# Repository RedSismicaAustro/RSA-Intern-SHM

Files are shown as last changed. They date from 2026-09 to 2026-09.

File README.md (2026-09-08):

# RSA Intern SHM

Repositorio para la **migración de proyectos electrónicos desde Altium Designer hacia KiCad 10** desarrollados para el sistema **RSA Structural Health Monitoring (SHM)**.

El propósito de este repositorio es preservar los diseños electrónicos existentes, reemplazar las bibliotecas propietarias utilizadas en Altium por bibliotecas locales compatibles con KiCad y establecer un flujo de trabajo estandarizado para el mantenimiento del hardware mediante herramientas de código abierto.

Como parte del proceso de migración, cada proyecto es revisado para verificar la integridad del esquemático y del PCB, actualizar las bibliotecas de símbolos y huellas, asociar modelos tridimensionales, asignar códigos **LCSC** a los componentes compatibles con **JLCPCB** y generar nuevamente todos los archivos necesarios para fabricación y ensamblaje automático.

La documentación específica de cada tarjeta se encuentra en la carpeta **Docs**, mientras que las bibliotecas compartidas se almacenan dentro de **KiCad/libs**, permitiendo reutilizar componentes entre diferentes proyectos y garantizando que cualquier desarrollador pueda abrir los diseños sin depender de configuraciones locales.

---

# Objetivos

El proceso de migración busca establecer una metodología uniforme para todos los proyectos electrónicos del sistema SHM. Los principales objetivos del repositorio son:

- Migrar los diseños electrónicos desde Altium Designer hacia KiCad 10.
- Eliminar dependencias de bibliotecas propietarias.
- Centralizar símbolos, footprints y modelos 3D en bibliotecas locales.
- Mantener todos los proyectos bajo control de versiones mediante Git.
- Preparar los diseños para fabricación y ensamblaje mediante JLCPCB.
- Documentar el proceso de migración para facilitar futuras modificaciones y revisiones.

---

# Estructura del repositorio

El repositorio se organiza de manera que cada proyecto conserve su propia documentación, mientras que las bibliotecas compartidas permanecen centralizadas para facilitar su reutilización.

```text
RSA-Intern-SHM/
│
├── Docs/
│   ├── Nodo/
│   │   └── README.md
│   ├── Concentrador/
│   │   └── README.md
│   ├── Concentrador2/
│   │   └── README.md
│   └── ...
│
├── KiCad/
│   ├── libs/
│   │   ├── RSA.kicad_sym
│   │   ├── RSA.pretty/
│   │   ├── LibExt.pretty/
│   │   └── packages3d/
│   │
│   └── projects/
│       ├── Nodo/
│       ├── Concentrador/
│       ├── Concentrador2/
│       └── ...
│
├── Firmware/
│
├── Production/
│
└── README.md
```

La carpeta `KiCad/projects` contiene los proyectos electrónicos migrados, mientras que `KiCad/libs` almacena todas las bibliotecas compartidas utilizadas por los diferentes diseños. Esta organización evita duplicar componentes y simplifica el mantenimiento de las bibliotecas a medida que nuevos proyectos son incorporados al repositorio.

---

# Herramientas utilizadas

La migración y mantenimiento de los proyectos se realiza utilizando herramientas de código abierto y utilidades complementarias para automatizar la generación de bibliotecas y archivos de fabricación.

| Herramienta | Descripción |
|---|---|
| KiCad 10 | Diseño y edición de esquemáticos y PCB |
| Python 3 | Automatización de herramientas auxiliares |
| Git | Control de versiones |
| JLC2KiCadLib | Descarga automática de símbolos, footprints y modelos 3D |
| Fabrication Toolkit | Generación de BOM, CPL, Gerbers y NC Drill |
| JLCPCB | Fabricación y ensamblaje PCBA |

---

# Flujo de migración

Todos los proyectos contenidos en este repositorio siguen un procedimiento de migración común con el objetivo de mantener una estructura uniforme y facilitar el mantenimiento futuro.

El proceso comienza con la importación del proyecto desde Altium Designer hacia KiCad. Posteriormente se realiza una revisión completa del esquemático y del PCB para verificar que las conexiones eléctricas, las referencias de componentes y las reglas de diseño hayan sido importadas correctamente.

Una vez validado el diseño, se sustituyen las bibliotecas originales por bibliotecas locales compatibles con KiCad. Cada símbolo queda asociado con su respectiva huella y, cuando está disponible, con su modelo tridimensional.

Posteriormente se revisan los componentes para identificar aquellos compatibles con el servicio PCBA de JLCPCB. A estos componentes se les asigna su correspondiente código LCSC, permitiendo automatizar la generación de la lista de materiales y del archivo de posicionamiento durante el proceso de fabricación.

Finalmente se ejecutan las verificaciones ERC y DRC, se generan los archivos Gerber, NC Drill, BOM y CPL mediante Fabrication Toolkit y se valida la documentación obtenida utilizando el visor de JLCPCB.

---

# Organización de bibliotecas

Uno de los principales objetivos de la migración consiste en eliminar la dependencia de bibliotecas instaladas globalmente. Para ello, todos los símbolos, footprints y modelos tridimensionales utilizados por los proyectos se almacenan dentro del repositorio.

Las bibliotecas principales utilizadas son:

- RSA.kicad_sym
- RSA.pretty
- LibExt.pretty

Los modelos tridimensionales asociados a cada componente se almacenan dentro de la carpeta `packages3d`, mientras que los componentes descargados automáticamente desde JLCPCB se incorporan a las bibliotecas locales mediante **JLC2KiCadLib**.

Esta organización garantiza que cualquier proyecto pueda abrirse correctamente después de clonar el repositorio, independientemente del equipo utilizado.

---

# Proyectos

Actualmente el repositorio contiene varias tarjetas electrónicas migradas desde Altium Designer hacia KiCad 10.

| Proyecto | Descripción |
|---|---|
| Nodo | Nodo de adquisición de datos del sistema SHM. |
| Concentrador | Tarjeta concentradora de comunicaciones. |
| Concentrador2 | Segunda revisión del concentrador con mejoras de hardware. |

Cada proyecto dispone de un archivo `README.md` independiente dentro de la carpeta `Docs`, donde se documenta el procedimiento de migración, la configuración de bibliotecas, la lista de componentes, los códigos LCSC y el proceso de generación de archivos de fabricación.

---

# Preparación para fabricación

Todos los diseños fueron preparados para ser fabricados utilizando el servicio **JLCPCB PCBA**. Los componentes compatibles emplean códigos **LCSC**, permitiendo automatizar la generación de la lista de materiales y el posicionamiento de componentes durante el ensamblaje.

Antes de generar los archivos de producción se revisan las propiedades de cada componente para configurar correctamente las opciones **Exclude from BOM** y **Exclude from Board**, evitando que conectores, elementos mecánicos o componentes de montaje manual sean incluidos en los archivos de ensamblaje.

La documentación de fabricación generada para cada proyecto incluye:

- Gerber
- NC Drill
- Bill of Materials (BOM)
- Component Placement List (CPL)

Estos archivos pueden almacenarse dentro de la carpeta `Production` correspondiente a cada diseño para facilitar futuras órdenes de fabricación.

---

# Buenas prácticas

Para mantener la consistencia del repositorio se recomienda utilizar exclusivamente las bibliotecas locales almacenadas en `KiCad/libs` y evitar referencias a bibliotecas instaladas globalmente. Asimismo, cualquier componente nuevo debe incorporar su correspondiente símbolo, huella y modelo tridimensional antes de ser utilizado en un proyecto.

Se recomienda ejecutar las verificaciones ERC y DRC antes de cada liberación, mantener actualizados los códigos LCSC de los componentes compatibles con JLCPCB y validar los archivos Gerber, BOM y CPL utilizando el visor web del fabricante antes de confirmar una orden de producción.

Toda modificación realizada sobre un proyecto o una biblioteca debe registrarse mediante Git para conservar el historial de cambios y facilitar la colaboración entre los diferentes integrantes del equipo.

---

# Documentación

La documentación específica de cada tarjeta se encuentra disponible dentro de la carpeta `Docs`.

- `Docs/Nodo/README.md`
- `Docs/Concentrador/README.md`
- `Docs/Concentrador2/README.md`

Cada documento describe detalladamente el proceso de migración, los componentes utilizados, la configuración de bibliotecas, la asignación de códigos LCSC y la generación de los archivos de fabricación correspondientes.

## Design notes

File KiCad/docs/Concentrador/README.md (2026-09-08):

# Proyecto Nodo

## Migración y preparación para fabricación PCBA en KiCad 10

## Introducción

El presente documento describe el procedimiento utilizado para migrar el **Proyecto Concentrador** desde Altium Designer hacia **KiCad 10**, estandarizar las bibliotecas empleadas durante el desarrollo y preparar el diseño para su fabricación y ensamblaje automático mediante el servicio **PCBA de JLCPCB**. El objetivo principal es que cualquier desarrollador pueda clonar el repositorio, configurar el entorno de trabajo y generar nuevamente los archivos de fabricación sin depender de configuraciones locales ni de software propietario.

Durante el proceso de migración se realizó la importación del diseño electrónico, la actualización de componentes de montaje superficial, la organización de bibliotecas locales, la asignación de códigos LCSC para los componentes compatibles con JLCPCB y la generación automática de símbolos, huellas y modelos tridimensionales mediante herramientas auxiliares. Finalmente, se validó el proyecto utilizando las herramientas de fabricación de KiCad para obtener los archivos requeridos por el servicio de ensamblaje.

Toda la estructura del proyecto fue diseñada para mantener una organización uniforme dentro del repositorio Git, evitando referencias a bibliotecas externas y garantizando que todos los recursos necesarios para abrir el proyecto se encuentren almacenados localmente.

---

# Estructura del proyecto

El repositorio se organiza siguiendo una estructura modular que separa la documentación, los diseños electrónicos, las bibliotecas, el firmware y los archivos de producción. Esta organización facilita el mantenimiento del proyecto y permite reutilizar las bibliotecas en otros diseños desarrollados dentro del mismo repositorio.

```text
RSA-Intern-SHM/
│
├── Docs/
│   └── Nodo/
│       └── README.md
│
├── KiCad/
│   ├── libs/
│   │   ├── RSA.kicad_sym
│   │   ├── RSA.pretty/
│   │   │   ├── *.kicad_mod
│   │   │   └── packages3d/
│   │   └── LibExt.pretty/
│   │
│   └── projects/
│       └── concentrador2/
│
├── Firmware/
│
└── Production/
```

La carpeta **KiCad/libs** almacena todas las bibliotecas utilizadas por el proyecto. En ella se encuentran los símbolos eléctricos, las huellas de PCB y los modelos tridimensionales descargados automáticamente desde JLCPCB o desarrollados manualmente. Gracias a esta organización, cualquier persona que clone el repositorio dispondrá inmediatamente de todos los recursos necesarios para abrir el proyecto sin realizar configuraciones adicionales.

---

# Configuración del entorno

Antes de comenzar la migración es necesario preparar el entorno de desarrollo. La herramienta principal utilizada durante todo el proceso es **KiCad 10**, la cual proporciona las utilidades necesarias para editar esquemáticos, diseñar tarjetas PCB, administrar bibliotecas y generar los archivos de fabricación. Se recomienda instalar la versión estable más reciente disponible para asegurar la compatibilidad con los formatos utilizados en este proyecto.

Como complemento, se emplea **Python 3.14** para ejecutar herramientas auxiliares destinadas a la descarga automática de bibliotecas electrónicas. Se recomienda crear un entorno virtual con el fin de aislar las dependencias del proyecto y evitar conflictos con otras aplicaciones instaladas en el sistema. Para ello puede ejecutarse el siguiente comando:

```powershell
python -m venv .venv
```

Una vez creado el entorno virtual, este debe activarse antes de instalar las dependencias necesarias.

```powershell
.venv\Scripts\activate
```

Posteriormente se recomienda actualizar el administrador de paquetes para garantizar la instalación de las versiones más recientes de cada dependencia.

```powershell
pip install --upgrade pip
```

Con el entorno preparado, se procede a instalar **JLC2KiCadLib**, una utilidad desarrollada para descargar automáticamente los símbolos eléctricos, footprints y modelos tridimensionales disponibles en la base de datos de JLCPCB a partir del código LCSC de cada componente. Esta herramienta simplifica considerablemente la creación de bibliotecas y reduce el tiempo requerido para preparar nuevos diseños.

Las dependencias pueden instalarse mediante los siguientes comandos:

```powershell
pip install kicadmodtree requests
pip install JLC2KiCadLib
```

Finalmente, es recomendable verificar que la instalación se haya realizado correctamente ejecutando:

```powershell
JLC2KiCadLib --help
```

Además de las herramientas anteriores, este proyecto utiliza el complemento **Fabrication Toolkit**, disponible desde el **Plugin and Content Manager (PCM)** de KiCad. Este complemento permite automatizar la generación de la lista de materiales (BOM), el archivo de posicionamiento de componentes (CPL), los archivos Gerber y el archivo de perforaciones (NC Drill), todos ellos compatibles con el proceso de fabricación y ensamblaje de JLCPCB. Una vez instalado el complemento, únicamente es necesario reiniciar KiCad para disponer de todas sus funcionalidades.

---

# Configuración de KiCad

Con el entorno completamente instalado, el siguiente paso consiste en registrar las bibliotecas locales utilizadas por el proyecto. A diferencia de otros flujos de trabajo donde las bibliotecas se instalan globalmente, en este proyecto todos los símbolos, footprints y modelos tridimensionales permanecen dentro del repositorio. Esta estrategia garantiza que cualquier modificación realizada sobre una biblioteca quede versionada junto con el resto del proyecto y evita incompatibilidades entre diferentes estaciones de trabajo.

En el administrador de bibliotecas de símbolos (**Preferences → Manage Symbol Libraries**) debe agregarse el archivo **RSA.kicad_sym**, ubicado dentro de la carpeta **KiCad/libs**. De forma similar, desde **Preferences → Manage Footprint Libraries** debe registrarse la biblioteca **RSA.pretty**, la cual contiene todas las huellas utilizadas por el diseño.

Para evitar referencias a rutas absolutas, también se recomienda definir la variable de entorno **RSA_LIBS**, apuntando al directorio **KiCad/libs**. Gracias a esta configuración, los modelos tridimensionales podrán localizarse utilizando rutas relativas como:

```text
${RSA_LIBS}/RSA.pretty/packages3d/
```

El uso de variables de entorno facilita la portabilidad del proyecto y evita que las referencias a modelos 3D deban modificarse cuando el repositorio es clonado en un nuevo equipo. De esta forma, el proyecto mantiene una estructura consistente y completamente independiente de la ubicación física donde haya sido almacenado.

---

# Migración del proyecto

Una vez configurado el entorno de desarrollo, se procede a importar el proyecto originalmente desarrollado en Altium Designer hacia KiCad 10. Durante esta etapa es importante verificar que tanto el esquemático como el diseño de la tarjeta de circuito impreso hayan sido convertidos correctamente, prestando especial atención a las referencias entre componentes, nombres de redes, jerarquías y asociaciones entre símbolos y huellas.

Aunque KiCad incorpora herramientas de importación compatibles con proyectos de Altium, es recomendable realizar una revisión completa del diseño una vez finalizada la conversión. En particular, deben verificarse las conexiones eléctricas, las reglas de diseño (DRC), la orientación de los componentes y la correcta asociación de cada símbolo con su respectiva huella. Esta revisión permite detectar posibles inconsistencias derivadas del proceso de conversión antes de continuar con la preparación para fabricación.

Durante la migración también se reorganizaron las bibliotecas del proyecto con el propósito de eliminar dependencias externas. Los símbolos y footprints que originalmente pertenecían a bibliotecas globales fueron reemplazados por versiones almacenadas dentro de la carpeta `KiCad/libs`, garantizando que el proyecto permanezca completamente autocontenido y pueda abrirse correctamente en cualquier equipo.

---

# Adaptación de componentes para ensamblaje PCBA

Con el proyecto ya migrado, el siguiente paso consiste en adaptar los componentes para que puedan ser ensamblados automáticamente por JLCPCB. Aunque muchos componentes utilizados originalmente poseen versiones de montaje superficial (SMD), algunos dispositivos fueron reemplazados por equivalentes compatibles con el proceso de ensamblaje automático, mientras que otros permanecieron como componentes de inserción (THT) debido a restricciones mecánicas o de disponibilidad.

Cada componente fue revisado individualmente para verificar la existencia de un código **LCSC**, ya que este identificador permite relacionar el diseño electrónico con la base de datos de componentes disponible en JLCPCB. En aquellos casos donde existía un reemplazo SMD funcionalmente equivalente, se actualizó el esquemático y el PCB para utilizar dicho componente. Cuando no existía una alternativa adecuada, el componente se mantuvo como montaje manual y se excluyó del proceso de ensamblaje automático.

Este procedimiento permitió maximizar la cantidad de componentes ensamblados durante la fabricación, reduciendo considerablemente el trabajo de soldadura manual posterior.

---

# Gestión de bibliotecas y componentes

Con la selección definitiva de componentes realizada, fue necesario organizar las bibliotecas utilizadas por el proyecto. Para ello se decidió centralizar todos los recursos dentro de una única biblioteca denominada **RSA**, donde se almacenan los símbolos eléctricos, footprints y modelos tridimensionales descargados desde JLCPCB.

La descarga automática de estos recursos se realizó mediante la herramienta **JLC2KiCadLib**, la cual utiliza el código LCSC de cada componente para obtener la información necesaria desde la base de datos oficial de JLCPCB. Gracias a este procedimiento fue posible generar bibliotecas consistentes y reutilizables sin necesidad de construir manualmente cada footprint o símbolo.

El comando utilizado para descargar las bibliotecas del proyecto fue el siguiente:

```powershell
& "$env:APPDATA\Python\Python314\Scripts\JLC2KiCadLib.exe" `
C481667 `
C2651511 `
C35879 `
C720477 `
C4410 `
C17902 `
C26010 `
C17900 `
C17936 `
C2290 `
C2128 `
C1525 `
C29266 `
C15195 `
C970695 `
C2858857 `
C70381 `
-dir "C:\Users\Suarezc1224\Desktop\RSA-Intern-SHM\KiCad\libs" `
-symbol_lib RSA `
-symbol_lib_dir . `
-footprint_lib RSA.pretty `
-model_dir packages3d `
--skip_existing
```

La ejecución de este comando genera automáticamente el archivo `RSA.kicad_sym`, la biblioteca de footprints `RSA.pretty` y la carpeta `packages3d`, donde se almacenan los modelos tridimensionales utilizados por el visualizador 3D de KiCad.

Una vez descargadas las bibliotecas, se recomienda revisar cada componente para verificar que tanto el símbolo como la huella y el modelo tridimensional hayan sido asociados correctamente. En algunos casos puede ser necesario ajustar manualmente la orientación del modelo 3D o reemplazar la huella por otra versión más adecuada al diseño de la tarjeta.

---

# Componentes utilizados

Los componentes empleados durante el desarrollo del Proyecto Nodo fueron seleccionados priorizando su disponibilidad dentro del catálogo de JLCPCB y la compatibilidad con el proceso de ensamblaje automático. Para cada componente se registró su código LCSC, fabricante, encapsulado y huella correspondiente dentro de KiCad, permitiendo automatizar la generación de la lista de materiales durante la fabricación.

| Componente | Voltaje | LCSC | Type | Package | Footprint | Name |
| --- | --- | --- | --- | --- | --- | --- |
| C_470uF | 16V | C2858857 | Extended | SMD,D8xL10.2mm | Capacitor_SMD:C_Elec_8x10.2 | C1 |
| C_220uF | 16V | C970695 | Extended | SMD,D6.3xL7.7mm | Capacitor_SMD:C_Elec_6.3x7.7 | C3 |
| C_100nF | 16V | C1525 | Basic | 0402 | Capacitor_SMD:C_0402_1005Metric | C2, C4, C5, C7, C8, C12, C13, C15 |
| C_10nF | 16V | C15195 | Basic | 0402 | Capacitor_SMD:C_0402_1005Metric | C6, C9 |
| C_1uF | 16V | C29266 | Extended | 0402 | Capacitor_SMD:C_0402_1005Metric | C10 |
| D_1N4148WS | 1N4148WS | C2128 | Basic | SOD-323 | Diode_SMD:D_SOD-323 | D3 |
| D_led_white | 2.6V~3.1V 360mcd 5mA | C2290 | Basic | 0603 | LED_SMD:LED_0603_1608Metric | D2, D4, D5 |
| MAX485ED | MAX485 | C481667 | Extended | SOP-8 | Package_SO:SOIC-8_3.9x4.9mm_P1.27mm | U4, U9 |
| DS3234S# | DS3234S# | C2651511 | Extended | SO-20-300mil | Package_SO:SOIC-20W_7.5x12.8mm_P1.27mm | U5 |
| LD1117S33CTR | LD33 | C35879 | Extended | SOT-223-4 | Package_TO_SOT_SMD:SOT-223-3_TabPin2 | U3 |
| B3U-1000P | Button | C720477 | Basic | SMD,4x3mm | Button_Switch_SMD:SW_SPST_B3U-1000P | S1 |
| R_1k | Res_250mW | C4410 | Basic | 1206 | Resistor_SMD:R_1206_3216Metric | R1, R16, R18 |
| R_3.3k | Res_125mW | C26010 | Basic | 0805 | Resistor_SMD:R_0805_2012Metric | R2, R5, R13, R14 |
| R_4.7k | Res_250mW | C17936 | Basic | 1206 | Resistor_SMD:R_1206_3216Metric | R3 |
| R_10k | Res_250mW | C17902 | Basic | 1206 | Resistor_SMD:R_1206_3216Metric | R15, R17 |
| R_100k | Res_250mW | C17900 | Basic | 1206 | Resistor_SMD:R_1206_3216Metric | R4 |
| CR1220 Battery Holder | CR1220 | C70381 | Extended | CR1220 | CR1220:CR1220-2 | BT2 |

La utilización de códigos LCSC simplifica el proceso de fabricación, ya que JLCPCB puede identificar automáticamente cada componente durante la generación de la orden de ensamblaje, reduciendo errores y evitando la selección manual de referencias equivalentes.

---

# Componentes sin código LCSC

No todos los dispositivos presentes en el proyecto forman parte del catálogo de componentes de JLCPCB. Algunos elementos corresponden a conectores, microcontroladores especializados o componentes mecánicos que deben instalarse manualmente una vez recibida la tarjeta ensamblada.

Estos componentes permanecen dentro del esquemático y del diseño PCB, pero no participan en el proceso automático de ensamblaje.

| Componente | Observación |
|---|---|
| dsPIC33EP256MC202 | Instalación manual |
| Pin Header 2x20 | Instalación manual |
| Pin Header 1x02 | Instalación manual |
| Conector RJ45 | Instalación manual |

La exclusión de estos dispositivos del proceso de ensamblaje no afecta la generación de la lista de materiales, siempre que se encuentren correctamente configurados mediante los campos correspondientes dentro del esquemático.

---

# Configuración de los campos del esquemático

Antes de generar los archivos de fabricación es recomendable revisar los campos asociados a cada componente del esquemático. Durante la migración desde Altium es habitual que se conserven propiedades provenientes de diferentes proveedores o herramientas de simulación que no aportan información relevante para el proceso de fabricación. Mantener únicamente los campos necesarios simplifica el mantenimiento del proyecto, evita información duplicada y facilita la generación de la lista de materiales.

Para este proyecto se conservaron únicamente los campos requeridos por KiCad, por el proceso de ensamblaje de JLCPCB y por las herramientas de simulación integradas. En consecuencia, cada componente debe contener únicamente los siguientes campos:

| Campo | Descripción |
|---|---|
| Reference | Identificador del componente. |
| Value | Valor o referencia comercial del componente. |
| Footprint | Huella utilizada en el PCB. |
| Datasheet | Hoja de datos del fabricante. |
| Description | Descripción del componente. |
| Qty | Cantidad utilizada en el proyecto. |
| # | Número de referencia interno. |
| LCSC | Código del componente en JLCPCB. |
| MANUFACTURER | Fabricante del componente. |
| MANUFACTURER_PART_NUMBER | Número de parte del fabricante. |
| PACKAGE | Encapsulado físico. |
| Sim.Device | Configuración de simulación. |
| Sim.Pins | Asociación de pines para simulación. |
| Sim.Type | Tipo de dispositivo para simulación. |
| DNP | Indica si el componente no debe ensamblarse. |
| Exclude from BOM | Excluye el componente de la lista de materiales. |
| Exclude from Board | Excluye el componente del PCB. |

Todos los demás campos, especialmente aquellos relacionados con distribuidores externos como Digi-Key, Mouser, Farnell, Newark, Purchase URL o referencias equivalentes, fueron eliminados para mantener una estructura uniforme en todo el proyecto. Esta limpieza facilita la edición del esquemático y evita inconsistencias durante la generación automática de la documentación de fabricación.

> **Nota:** Se recomienda incluir en esta sección la captura de pantalla correspondiente a la configuración de campos utilizada durante el desarrollo del proyecto.

---

# Generación de archivos de fabricación

Una vez verificado el esquemático y completada la asignación de códigos LCSC, el proyecto se encuentra listo para generar la documentación necesaria para fabricación y ensamblaje. Para ello se emplea el complemento **Fabrication Toolkit**, integrado en KiCad, el cual automatiza la generación de todos los archivos requeridos por JLCPCB. Antes de ello es importante excluir los elementos necesarios de los archivos de producción dentro de las propiedades del elemento.
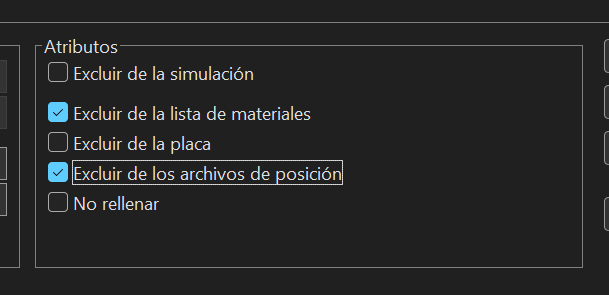
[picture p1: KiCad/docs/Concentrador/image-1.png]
Configuración de exclusión de componentes


Desde el editor de PCB se ejecuta el complemento y se selecciona el fabricante **JLCPCB** como destino. A continuación se generan de forma automática los archivos Gerber, el archivo de perforaciones (NC Drill), la lista de materiales (BOM) y el archivo de posicionamiento de componentes (CPL). El uso de esta herramienta garantiza que todos los archivos sean compatibles con el formato esperado por el servicio de fabricación, reduciendo significativamente la posibilidad de errores derivados de configuraciones manuales.

Una vez generados los archivos, se recomienda almacenarlos dentro de la carpeta `Production` del repositorio. De esta manera, toda la documentación relacionada con la fabricación permanece organizada y puede recuperarse fácilmente para futuras revisiones o nuevas órdenes de producción.
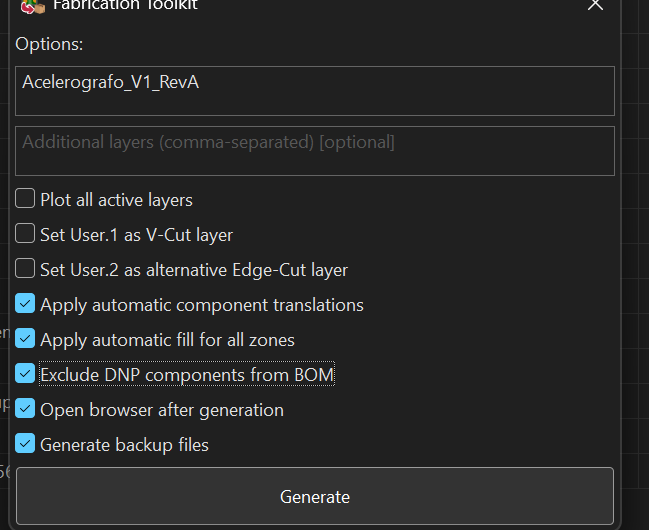
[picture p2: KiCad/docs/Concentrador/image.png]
Generación de archivos mediante Fabrication Toolkit


---

# Validación en JLCPCB

Antes de enviar el diseño a fabricación es recomendable realizar una validación completa utilizando el visor web de JLCPCB. Durante esta etapa se verifica que todos los componentes reconocidos mediante el código LCSC aparezcan correctamente asociados y que las orientaciones indicadas en el archivo CPL coincidan con la disposición física del PCB.

Asimismo, deben revisarse cuidadosamente las capas del diseño, el contorno de la tarjeta, los orificios de montaje, las dimensiones generales y cualquier advertencia generada por la plataforma de fabricación. En caso de detectarse componentes con orientación incorrecta, estos pueden corregirse directamente en KiCad y volver a generar el archivo CPL sin necesidad de modificar el resto de la documentación.

Esta validación constituye el último paso antes de confirmar la orden de fabricación y permite reducir considerablemente la probabilidad de errores durante el ensamblaje automático.

---

# Buenas prácticas

Durante el desarrollo del proyecto se adoptaron una serie de prácticas orientadas a facilitar el mantenimiento del repositorio y garantizar la reproducibilidad del diseño. Todas las bibliotecas utilizadas se almacenan localmente dentro del repositorio, evitando dependencias con bibliotecas instaladas en el sistema operativo. De igual forma, se emplean variables de entorno para referenciar los modelos tridimensionales, permitiendo que el proyecto pueda abrirse correctamente desde cualquier ubicación sin modificar rutas internas.

Se recomienda mantener actualizadas las bibliotecas únicamente cuando sea necesario incorporar nuevos componentes y evitar modificar las huellas descargadas automáticamente, salvo que exista una justificación técnica. En caso de requerir modificaciones específicas, es preferible crear una copia dentro de la biblioteca local para preservar la integridad de los componentes originales.

Finalmente, antes de cada liberación del proyecto, es aconsejable ejecutar las verificaciones ERC y DRC de KiCad, comprobar la correspondencia entre el esquemático y el PCB, revisar la lista de materiales generada y validar nuevamente los archivos de fabricación mediante el visor de JLCPCB.

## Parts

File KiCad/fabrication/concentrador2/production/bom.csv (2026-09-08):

Designator | Footprint | Quantity | Value | LCSC Part #
BT2 | CR1220-2-ext | 1 | Battery | C70381
C1 | C_Elec_8x10.2 | 1 | 470uF | C2858857
C10 | 0402 | 1 | 1uF | C29266
C12, C13, C15, C2, C4, C5, C7, C8 | 0402 | 8 | 100nF | C1525
C3 | C_Elec_6.3x7.7 | 1 | 220uF | C970695
C6, C9 | 0402 | 2 | 10nF | C15195
D2, D4, D5 | 0603 | 3 | LED_white | C2290
D3 | D_SOD-323 | 1 | 1N4148WS | C2128
R1, R16, R18 | 1206 | 3 | 1K | C4410
R13, R14, R2, R5 | 0805 | 4 | 3K3 | C26010
R15, R17 | 1206 | 2 | 10k | C17902
R3 | 1206 | 1 | 4K7 | C17936
R4 | 1206 | 1 | 100K | C17900
S1 | SW_SPST_B3U-1000P | 1 | SW-PB | C720477
U3 | SOT-223-3_TabPin2 | 1 | LD33V | C35879
U4, U9 | SOIC-8_3.9x4.9mm_P1.27mm | 2 | MAX485 | C481667
U5 | SOIC-20W_7.5x12.8mm_P1.27mm | 1 | DS3234S# | C2651511

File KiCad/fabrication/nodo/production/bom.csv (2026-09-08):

Designator | Footprint | Quantity | Value | LCSC Part #
C1 | C_Elec_8x10.2 | 1 | Cap | C2858857
C10 | 0402 | 1 | Cap | C29266
C11, C13, C16, C2, C4, C5, C7, C8 | 0402 | 8 | Cap | C1525
C3 | C_Elec_6.3x7.7 | 1 | Cap | C970695
C6, C9 | 0402 | 2 | Cap | C15195
D1 | D_SOD-323 | 1 | 1N4148WS | C2128
D3 | 0603 | 1 | LED3 | C2290
J1 | microSD | 1 | ${ALTIUM_VALUE}${VALUEAUX}
J2, J3 | RJ45_Amphenol_54602-x08_Horizontal | 2 | 54602-908LF
P1 | HDR1X6 | 1 | Grabador
R1, R13, R14, R2 | 1206 | 4 | Res1 | C26010
R3 | 1206 | 1 | Res1 | C17936
R4 | 1206 | 1 | Res1 | C17902
R6 | 1206 | 1 | Res1 | C4410
U1 | MCHP-SPDIP-SP28 | 1 | DSPIC33EP256MC202-I/SP
U2 | TO-252-3_TabPin2 | 1 | LM1117DT-5.0NOPB | C354068
U3 | SOT-223-3_TabPin2 | 1 | LD33V | C35879
U4 | ADXL355Z | 1 | ADXL355Z
U5, U9 | SOIC-8_3.9x4.9mm_P1.27mm | 2 | MAX485 | C481667
U6 | TO-263-2 | 1 | LM7805_TO220 | C15077

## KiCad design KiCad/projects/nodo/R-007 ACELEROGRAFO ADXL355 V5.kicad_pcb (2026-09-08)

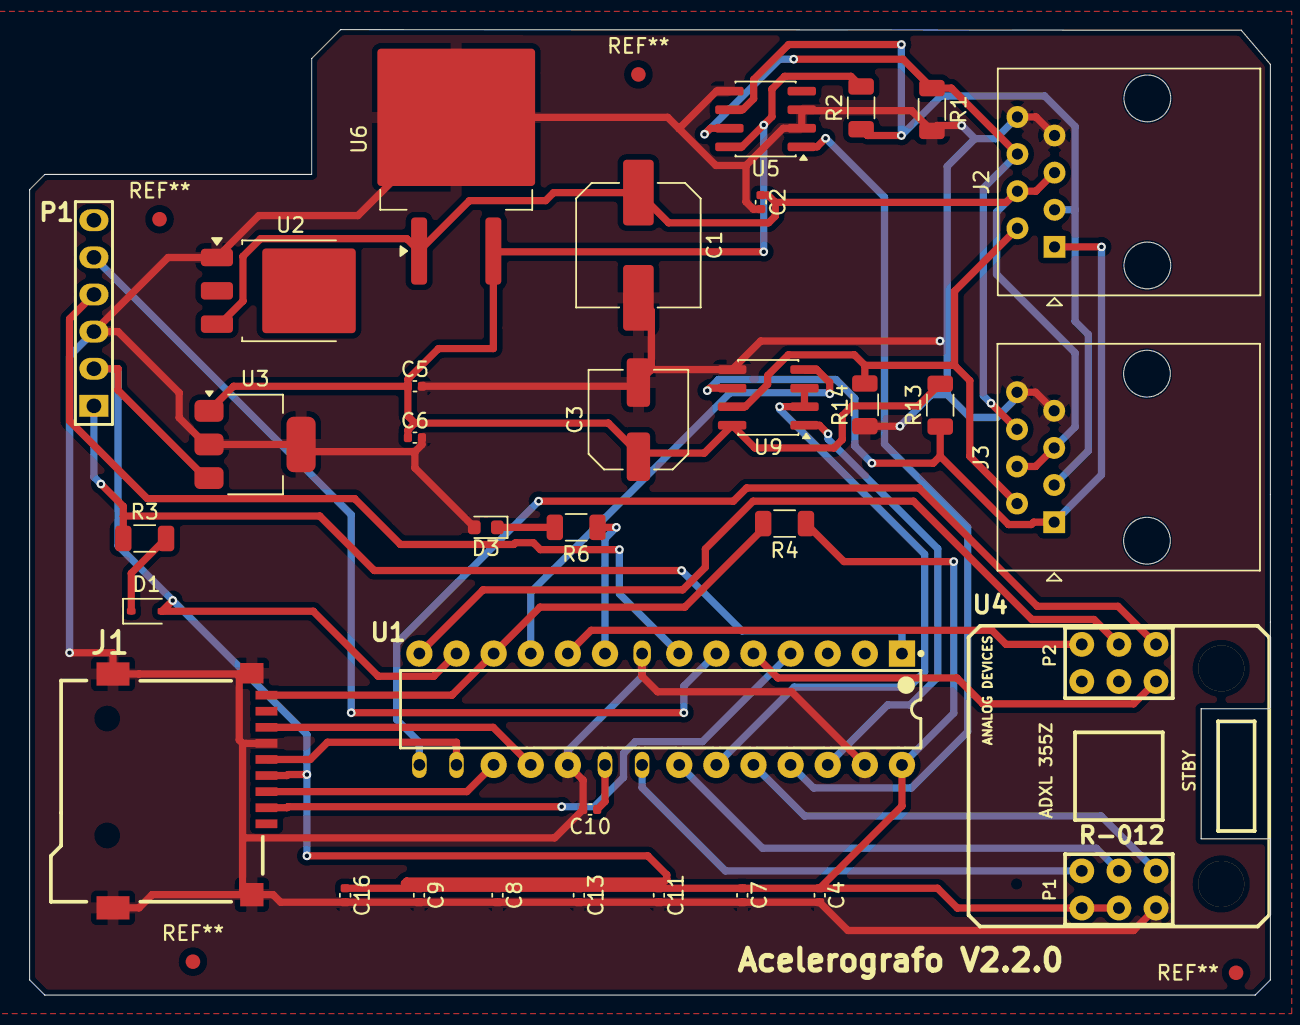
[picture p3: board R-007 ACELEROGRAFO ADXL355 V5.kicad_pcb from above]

Board: 2 copper layers, 84.9 x 66.1 mm, 33 parts (0 on the bottom side), 31 nets.

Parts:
C1: Cap; C_Elec_8x10.2
C2, C4, C5, C6, C7, C8, C9, C10, C11, C13, C16: Cap; C_0402_1005Metric
C3: Cap; C_Elec_6.3x7.7
D1: 1N4148WS; D_SOD-323
D3: LED3; LED_0603_1608Metric
J1: ${ALTIUM_VALUE}${VALUEAUX}; microSD
J2, J3: 54602-908LF; RJ45_Amphenol_54602-x08_Horizontal
P1: Grabador; HDR1X6
R1, R2, R3, R4, R6, R13, R14: Res1; R_1206_3216Metric
U1: DSPIC33EP256MC202-I/SP; MCHP-SPDIP-SP28
U2: LM1117DT-5.0NOPB; TO-252-3_TabPin2
U3: LD33V; SOT-223-3_TabPin2
U4: ADXL355Z
U5, U9: MAX485; SOIC-8_3.9x4.9mm_P1.27mm
U6: LM7805_TO220; TO-263-2

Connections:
5V: C3.1, C5.1, C6.1, R2.2, R13.2, U3.1 (IN), U5.8, U6.3 (VO), U9.8
A: J2.1, J3.1, R13.1, U9.6
ADXL_DRDY: U1.24 (RPI45/PWM2L/CTPLS/RB13), U4.3 (DRDY)
ADXL_INT1: U1.21 (TDO/RP42/PWM3H/RB10), U4.1 (INT1)
ADXL_INT2: U1.22 (TDI/RP43/PWM3L/RB11), U4.2 (INT2)
B: J2.2, J3.2, R14.1, U9.7
ConSD: J1.9 (SH), R4.2, U1.12 (CVREF2O/RP20/T1CK/RA4)
DSPIC_RX: U1.26 (RPI47/PWM1L/T5CK/RB15), U9.1
DSPIC_TX: U1.11 (FLT32/RP36/RB4), U9.4
FUENTE_12V: C1.1, C2.1, J2.4, J2.5, J3.4, J3.5, U2.3 (INPUT), U6.1 (VI)
GND: C1.2, C2.2, C3.2, C4.2, C5.2, C6.2, C7.2, C8.2, C9.2, C10.2, C11.2, C13.2, C16.2, D3.2 (K), J1.6 (GND), J1.10 (CD), J2.7, J2.8, J3.7, J3.8, P1.3, R1.2, R14.2, U1.8 (VSS), U1.19 (VSS), U1.27 (AVSS), U2.1 (GND), U3.2 (GND), U4.6 (GND), U5.2, U5.3, U5.5, U6.2 (GND), U9.5
INT_SINC: U1.25 (RPI46/PWM1H/T3CK/RB14), U5.1
MAX485_MS: U1.23 (RPI44/PWM2H/RB12), U9.2, U9.3
MCLR: P1.1, R3.1, U1.1 (~MCLR)
unnamed: D1.1 (K), R3.2
unnamed: D3.1 (A), R6.2
unnamed: C10.1, U1.20 (VCAP)
SINC_A: J2.3, J3.3, R2.1, U5.6
SINC_B: J2.6, J3.6, R1.1, U5.7
SPI1_DSPIC_SS: J1.2 (CD/DAT3), U1.4 (PGED3/VREF-/AN2/C2IN1-/~SS1/RPI32/CTED2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)
SPI1_MISO: J1.7 (DAT0), U1.18 (TMS/ASDA1/SDI1/RP41/RB9)
SPI1_MOSI: J1.3 (CMD), U1.17 (TCK/CVREF1O/ASCL1/SDO1/RP40/T4CK/RB8)
SPI1_SCK: J1.5 (CLK), U1.16 (SCK1/RP39/INT0/RB7)
SPI2_ADXL355Z_CS: U1.10 (OSC2/CLKO/RA3), U4.7 (CS/SCL)
SPI2_MISO: U1.5 (PGEC3/VREF+/AN3/OA1OUT/RPI33/CTED1/RB1), U4.12 (MISO/SDA)
SPI2_MOSI: U1.15 (PGEC2/ASCL2/RP38/RB6), U4.9 (MOSI/SDA)
SPI2_SCK: U1.14 (PGED2/ASDA2/RP37/RB5), U4.8 (SCLK/GND)
TEST1: R6.1, U1.9 (OSC1/CLKI/RA2)
VCC: C4.1, C7.1, C8.1, C9.1, C11.1, C13.1, C16.1, D1.2 (A), J1.4 (VDD), P1.2, R4.1, U1.13 (VDD), U1.28 (AVDD), U3.3 (OUT), U4.4 (VDDIO), U4.5 (VDD)
_PGEC1: P1.5, U1.6 (PGEC1/AN4/C1IN1+/RPI34/RB2)
_PGED1: P1.4, U1.7 (PGED1/AN5/C1IN1-/RP35/RB3)

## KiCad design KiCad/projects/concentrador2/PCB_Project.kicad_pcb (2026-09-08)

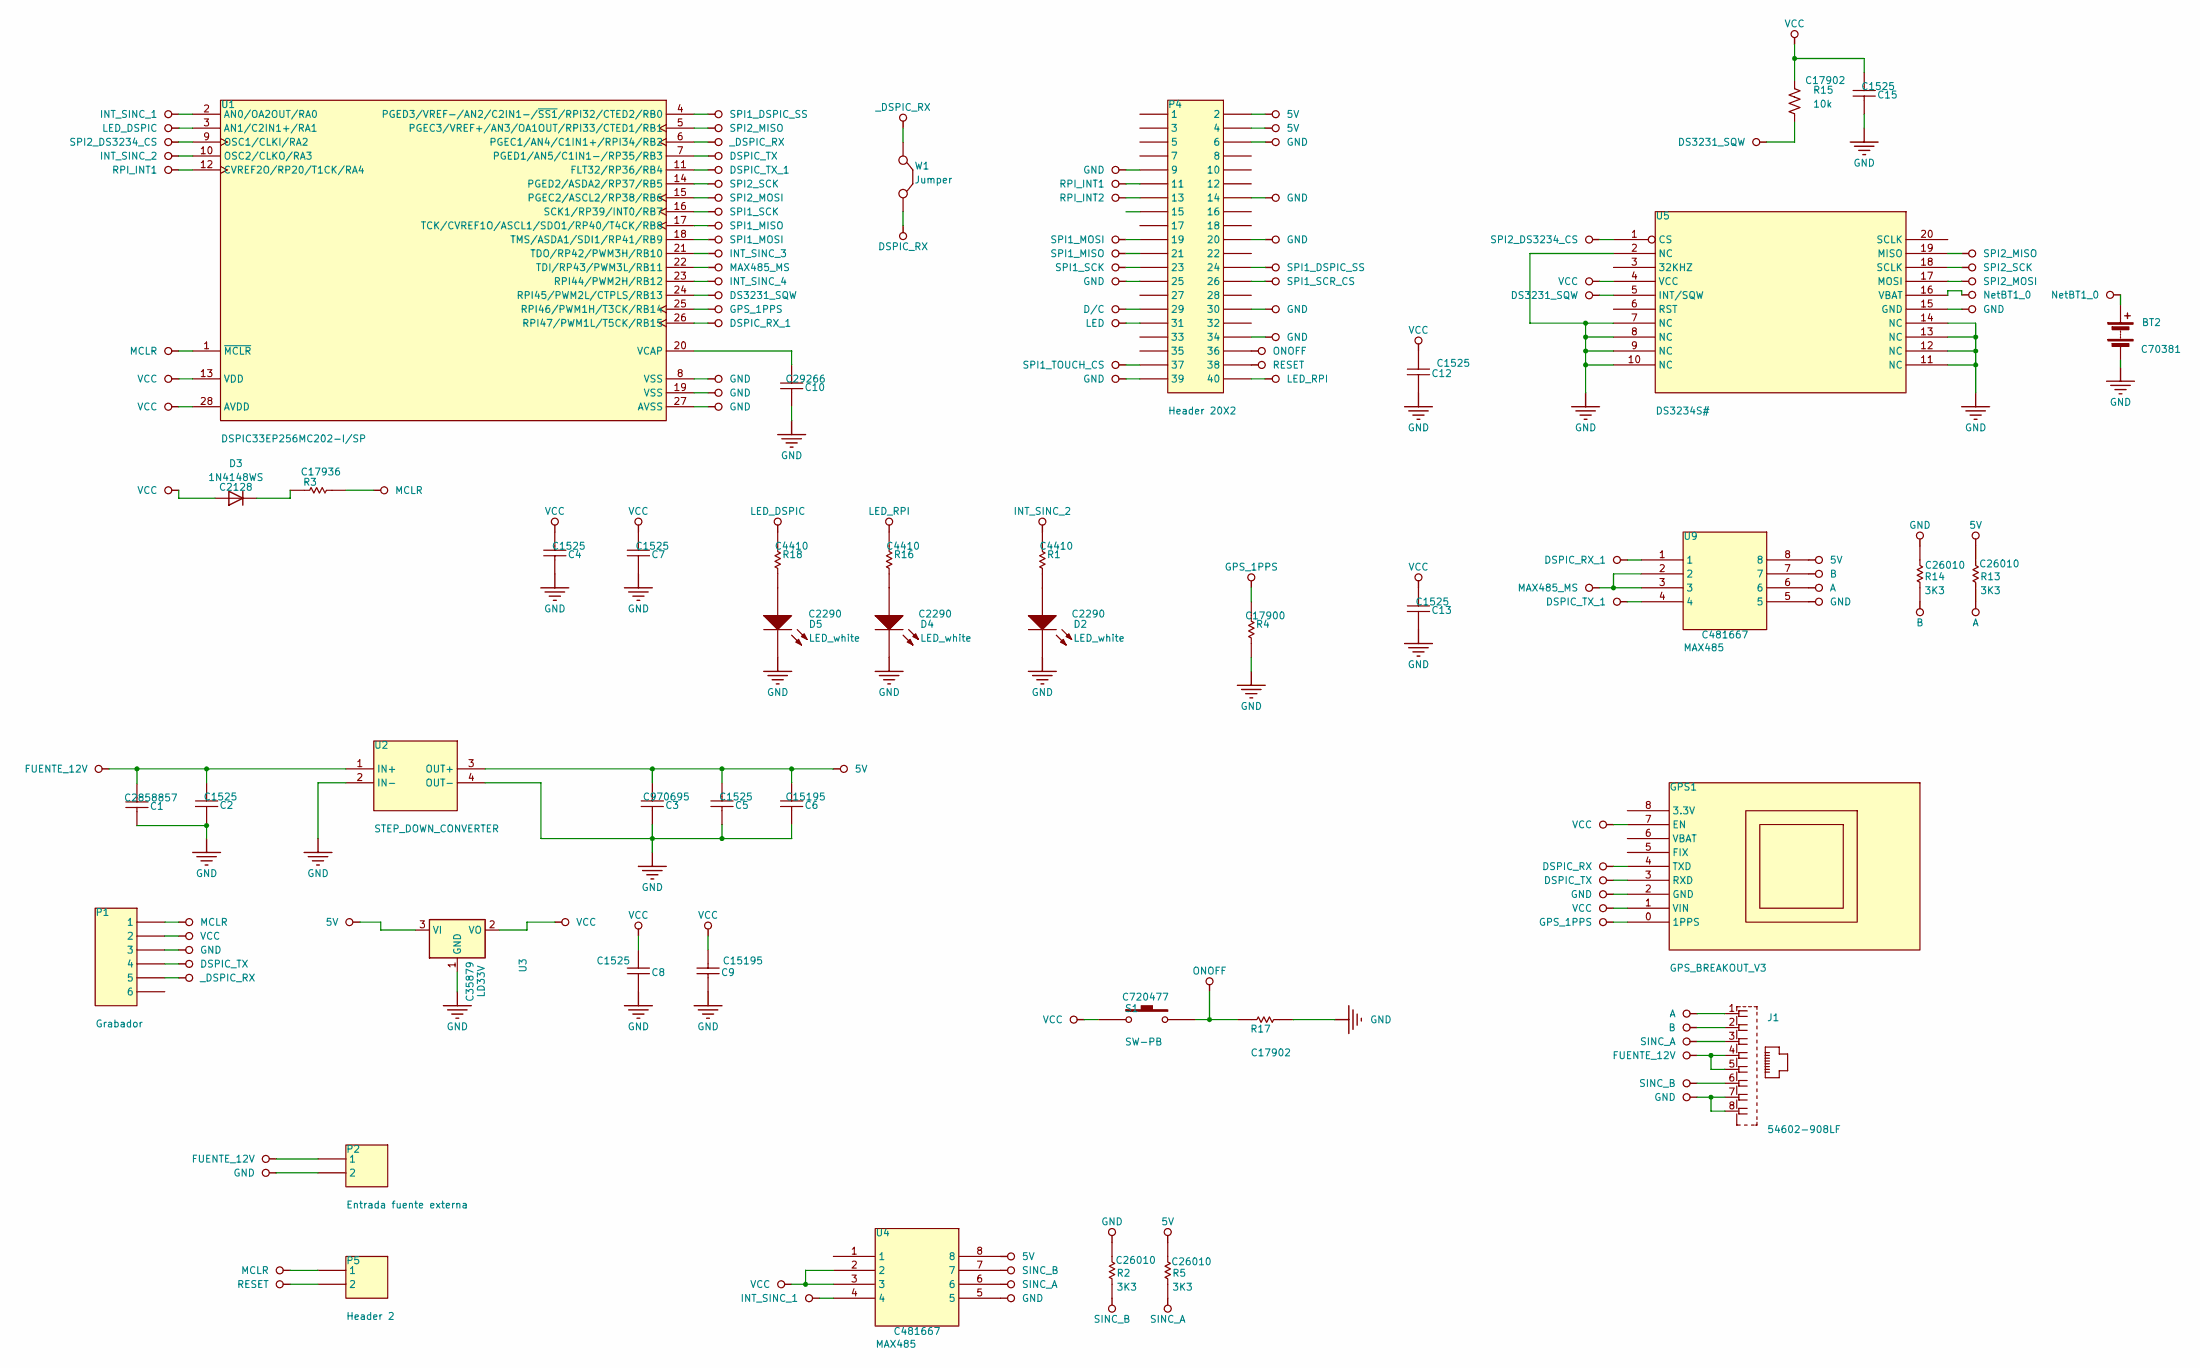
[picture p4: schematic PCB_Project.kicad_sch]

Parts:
BT2: Battery; CR1220-2; LCSC C70381
C1: 470uF; C_Elec_8x10.2; LCSC C2858857
C2, C4, C5, C7, C8, C12, C13, C15: 100nF; C_0402_1005Metric; LCSC C1525
C3: 220uF; C_Elec_6.3x7.7; LCSC C970695
C6, C9: 10nF; C_0402_1005Metric; LCSC C15195
C10: 1uF; C_0402_1005Metric; LCSC C29266
D2, D4, D5: LED_white; LED_0603_1608Metric; LCSC C2290
D3: 1N4148WS; D_SOD-323; LCSC C2128
GPS1: GPS_BREAKOUT_V3
J1: 54602-908LF; RJ45_Amphenol_54602-x08_Horizontal
P1: Grabador; PinHeader_1x06_P2.54mm_Vertical
P2: Entrada fuente externa; JST_XH_B2B-XH-A_1x02_P2.50mm_Vertical
P4: Header 20X2; PinHeader_2x20_P2.54mm_Vertical
P5: Header 2; PinHeader_1x02_P2.54mm_Vertical
R1, R16, R18: 1K; R_1206_3216Metric; LCSC C4410
R2, R5, R13, R14: 3K3; R_0805_2012Metric; LCSC C26010
R3: 4K7; R_1206_3216Metric; LCSC C17936
R4: 100K; R_1206_3216Metric; LCSC C17900
R15: 10k; R_1206_3216Metric; LCSC C17902
R17: 10K; R_1206_3216Metric; LCSC C17902
S1: SW-PB; SW_SPST_B3U-1000P; LCSC C720477
U1: DSPIC33EP256MC202-I/SP; DIP-28_W7.62mm_LongPads
U2: STEP_DOWN_CONVERTER
U3: LD33V; SOT-223-3_TabPin2; LCSC C35879
U4, U9: MAX485; SOIC-8_3.9x4.9mm_P1.27mm; LCSC C481667
U5: DS3234S#; SOIC-20W_7.5x12.8mm_P1.27mm; MANUFACTURER_PART_NUMBER DS3234S#; LCSC C2651511
W1: Jumper; PinHeader_1x02_P2.54mm_Vertical

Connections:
5V: C3.1, C5.1, C6.1, P4.2, P4.4, R5.2, R13.2, U2.3 (OUT+), U3.3 (VI), U4.8, U9.8
A: J1.1, R13.1, U9.6
B: J1.2, R14.1, U9.7
DS3231_SQW: R15.1, U1.24 (RPI45/PWM2L/CTPLS/RB13), U5.5 (INT/SQW)
DSPIC_RX: GPS1.4 (TXD), W1.2 (C2)
DSPIC_RX_1: U1.26 (RPI47/PWM1L/T5CK/RB15), U9.1
DSPIC_TX: GPS1.3 (RXD), P1.4, U1.7 (PGED1/AN5/C1IN1-/RP35/RB3)
DSPIC_TX_1: U1.11 (FLT32/RP36/RB4), U9.4
D/C: P4.29
FUENTE_12V: C1.1, C2.1, J1.4, J1.5, P2.1, U2.1 (IN+)
GND: BT2.2 (-), C1.2, C2.2, C3.2, C4.2, C5.2, C6.2, C7.2, C8.2, C9.2, C10.2, C12.2, C13.2, C15.2, D2.2 (K), D4.2 (K), D5.2 (K), GPS1.2 (GND), J1.7, J1.8, P1.3, P2.2, P4.6, P4.9, P4.14, P4.20, P4.25, P4.30, P4.34, P4.39, R2.2, R4.2, R14.2, R17.2, U1.8 (VSS), U1.19 (VSS), U1.27 (AVSS), U2.2 (IN-), U2.4 (OUT-), U3.1 (GND), U4.5, U5.2 (NC), U5.7 (NC), U5.8 (NC), U5.9 (NC), U5.10 (NC), U5.11 (NC), U5.12 (NC), U5.13 (NC), U5.14 (NC), U5.15 (GND), U9.5
GPS_1PPS: GPS1.0 (1PPS), R4.1, U1.25 (RPI46/PWM1H/T3CK/RB14)
INT_SINC_1: U1.2 (AN0/OA2OUT/RA0), U4.4
INT_SINC_2: R1.1, U1.10 (OSC2/CLKO/RA3)
INT_SINC_3: U1.21 (TDO/RP42/PWM3H/RB10)
INT_SINC_4: U1.23 (RPI44/PWM2H/RB12)
LED: P4.31
LED_DSPIC: R18.1, U1.3 (AN1/C2IN1+/RA1)
LED_RPI: P4.40, R16.1
MAX485_MS: U1.22 (TDI/RP43/PWM3L/RB11), U9.2, U9.3
MCLR: P1.1, P5.1, R3.1, U1.1 (~MCLR)
unnamed: D2.1 (A), R1.2
unnamed: D3.1 (K), R3.2
unnamed: D4.1 (A), R16.2
unnamed: D5.1 (A), R18.2
unnamed: C10.1, U1.20 (VCAP)
NetBT1_0: BT2.1 (+), U5.16 (VBAT)
ONOFF: P4.36, R17.1, S1.2
RESET: P4.38, P5.2
RPI_INT1: P4.11, U1.12 (CVREF2O/RP20/T1CK/RA4)
RPI_INT2: P4.13
SINC_A: J1.3, R5.1, U4.6
SINC_B: J1.6, R2.1, U4.7
SPI1_DSPIC_SS: P4.24, U1.4 (PGED3/VREF-/AN2/C2IN1-/~SS1/RPI32/CTED2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)
SPI1_MISO: P4.21, U1.17 (TCK/CVREF1O/ASCL1/SDO1/RP40/T4CK/RB8)
SPI1_MOSI: P4.19, U1.18 (TMS/ASDA1/SDI1/RP41/RB9)
SPI1_SCK: P4.23, U1.16 (SCK1/RP39/INT0/RB7)
SPI1_SCR_CS: P4.26
SPI1_TOUCH_CS: P4.37
SPI2_DS3234_CS: U1.9 (OSC1/CLKI/RA2), U5.1 (CS)
SPI2_MISO: U1.5 (PGEC3/VREF+/AN3/OA1OUT/RPI33/CTED1/RB1), U5.19 (MISO)
SPI2_MOSI: U1.15 (PGEC2/ASCL2/RP38/RB6), U5.17 (MOSI)
SPI2_SCK: U1.14 (PGED2/ASDA2/RP37/RB5), U5.18 (SCLK)
VCC: C4.1, C7.1, C8.1, C9.1, C12.1, C13.1, C15.1, D3.2 (A), GPS1.1 (VIN), GPS1.7 (EN), P1.2, R15.2, S1.1, U1.13 (VDD), U1.28 (AVDD), U3.2 (VO), U4.2, U4.3, U5.4 (VCC)
_DSPIC_RX: P1.5, U1.6 (PGEC1/AN4/C1IN1+/RPI34/RB2), W1.1 (C1)

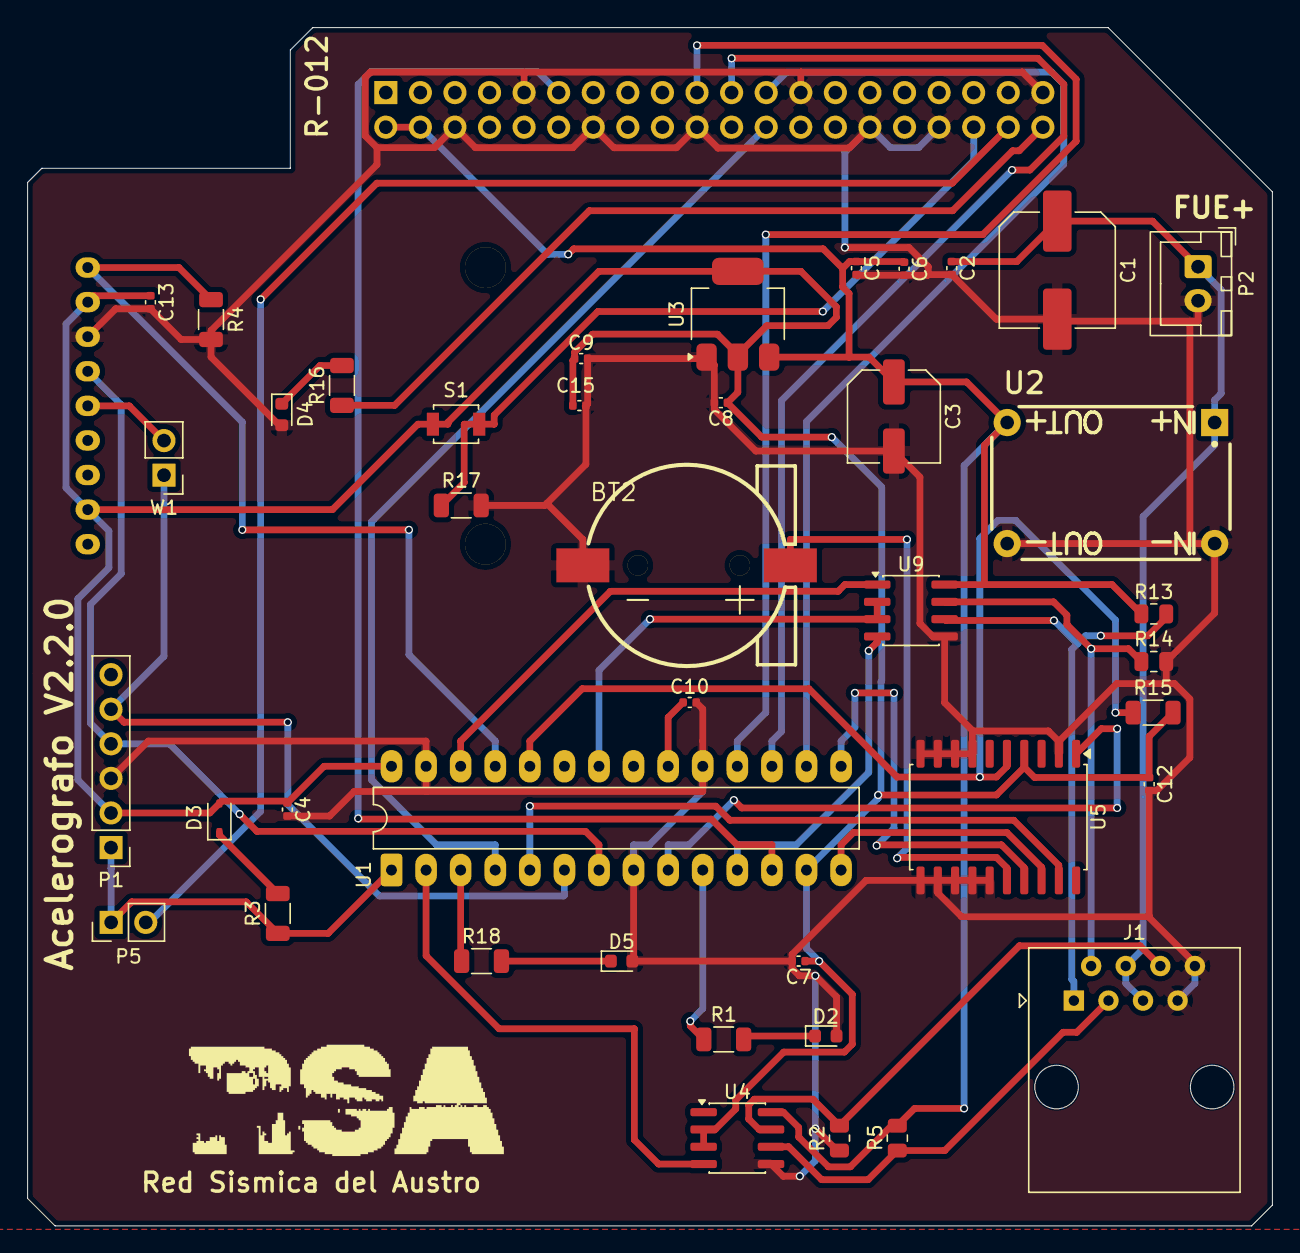
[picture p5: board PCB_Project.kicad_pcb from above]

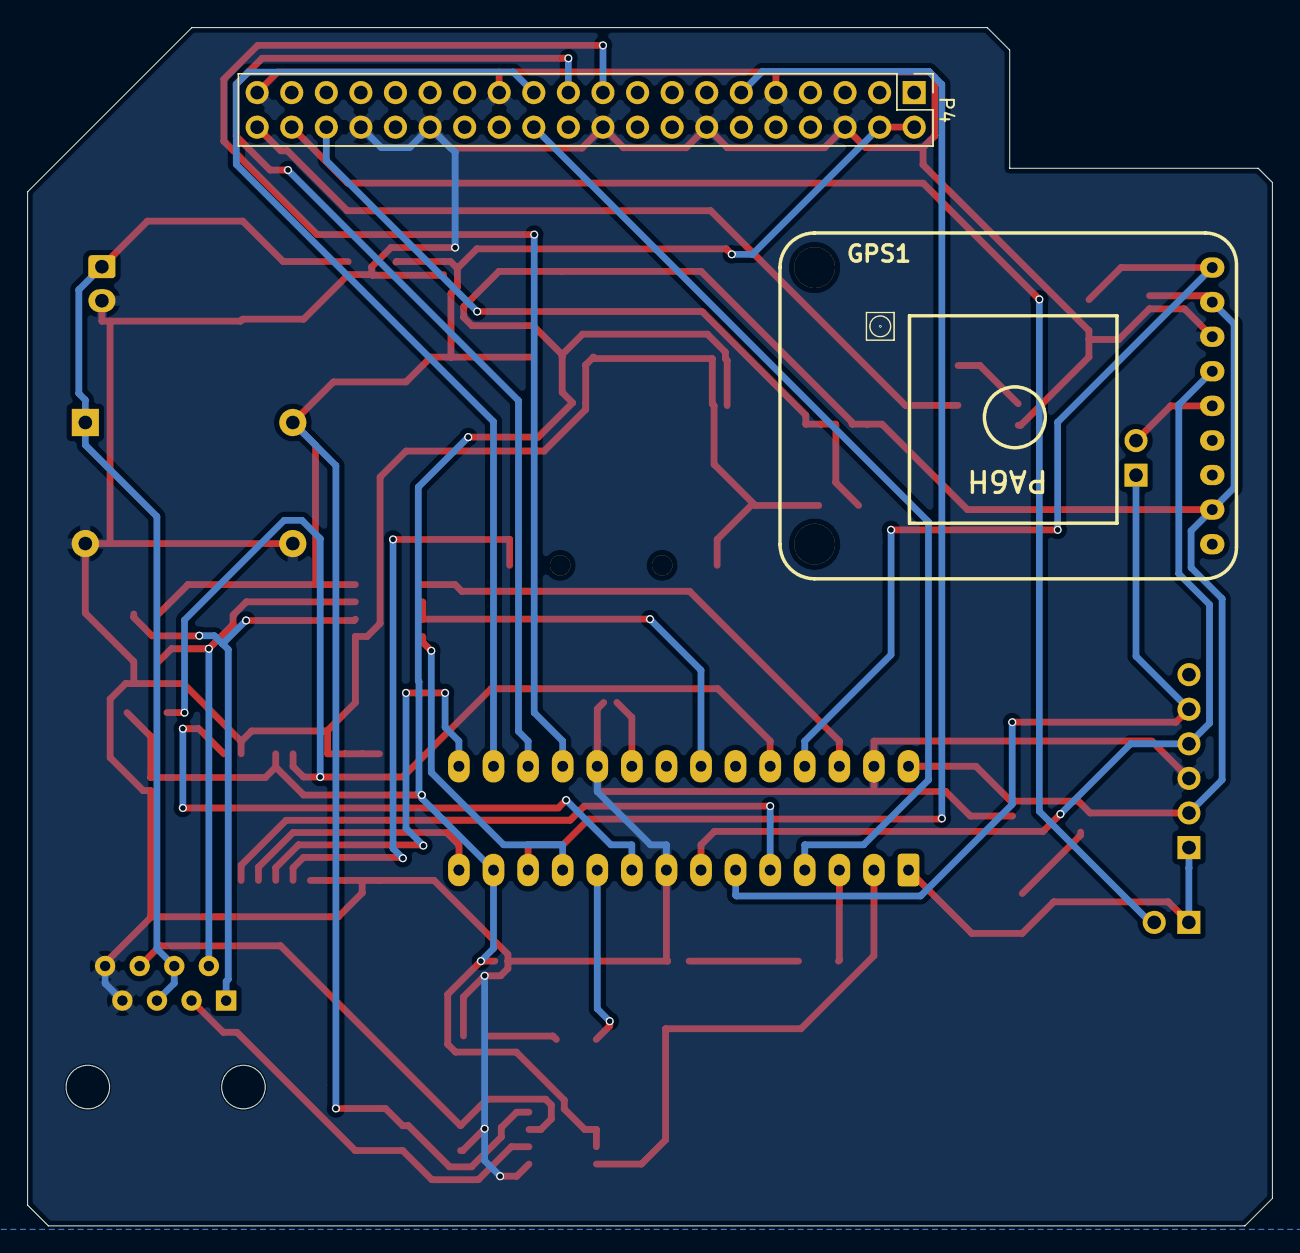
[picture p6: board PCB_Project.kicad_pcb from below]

Board: 2 copper layers, 91.4 x 88.0 mm, 43 parts (2 on the bottom side), 38 nets.

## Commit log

2026-04-20 init: Inicio del proyecto - Se agregaron los archivos de Altium del concentrador - Se agrego el archivo gitignore
    [PCB1.PcbDoc, PCB_Project.PrjPcb, PcbLib1.PcbLib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]
2026-04-21 Agrega estructura base KiCad
2026-04-22 Importación inicial del proyecto concentrador desde Altium a KiCad
    [PCB_Project.kicad_pcb, PCB_Project.kicad_sch, Schlib1.SchLib]
2026-04-24 docs: Se agregaron los archivos de Altium del nodo
    [Esquema.SchDoc, PCB.PcbDoc, PcbLib1.PcbLib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]
2026-05-06 Migracion a SMD
    [PCB_Project.kicad_pcb, PCB_Project.kicad_sch]
2026-05-06 Ignora carpetas de historial local
2026-05-11 Fase 3
    [PCB_Project.kicad_sch]
2026-06-03 Fase 4 - Asignación para PCBA
    [PCB_Project.kicad_pcb, PCB_Project.kicad_sch]
2026-06-04 Fase 4 - 2
    [PCB_Project.kicad_pcb, PCB_Project.kicad_sch]
2026-06-11 Archivos Gerber
    [Acelerografo_V1_RevA_bom.csv, Acelerografo_V1_RevA_designators.csv, Acelerografo_V1_RevA_positions.csv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]
2026-07-06 Agregar proyecto Nodo
    [R-007 ACELEROGRAFO ADXL355 V5.kicad_pcb, R-007 ACELEROGRAFO ADXL355 V5.kicad_sch]
2026-07-07 PCB Acelerografo & Nodo
    [Acelerografo_V1_RevA_positions.csv, Esquema.SchDoc, PCB.PcbDoc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]
2026-07-15 Cambios Finales en PCB's
    [Acelerografo_V1_RevA_bom.csv, Acelerografo_V1_RevA_designators.csv, Acelerografo_V1_RevA_positions.csv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]
2026-07-30 Cambios en el PCB
    [Acelerografo_V1_RevA_bom.csv, Acelerografo_V1_RevA_designators.csv, Acelerografo_V1_RevA_positions.csv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]
